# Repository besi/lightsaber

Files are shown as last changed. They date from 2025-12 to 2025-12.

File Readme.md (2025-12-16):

# Lightsaber

This is my lightsaber featuring a custom made PCB and as Neopixel strip.

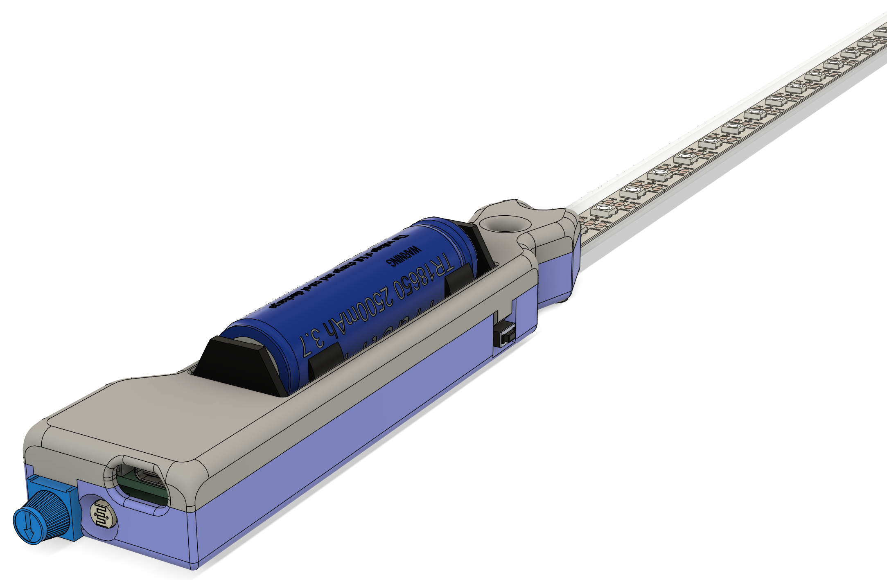
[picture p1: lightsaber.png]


## Pinout of the wemos c3 pico

| Function | Pin |
|---|----:|
| Neopixelstrip | 2 |
| Mode button | 5 |
| Internal RGB* | 7 |
| Potentiometer | 1 |
| Batteryvoltage**  | 3 |

\* This is a GRB instead of RGB LED
\** This requires a solder jumper on the back of the C3 board

## Credits

- 3D model of the 18650 battery by John Michael Loeffler

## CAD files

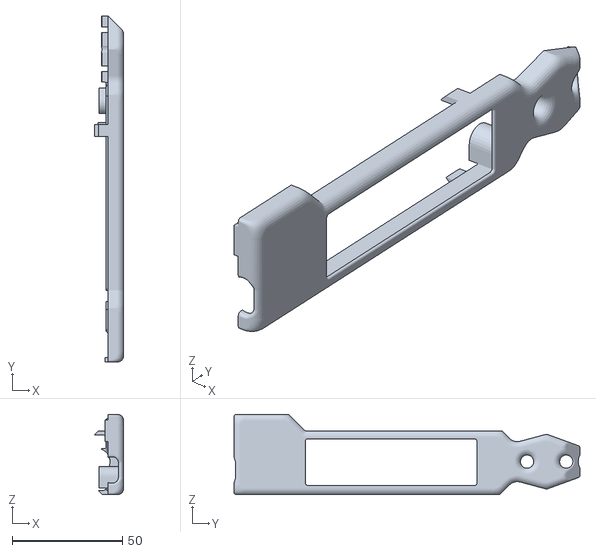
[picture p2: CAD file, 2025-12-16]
stl/top.stl
13.3 x 157.2 x 36.5

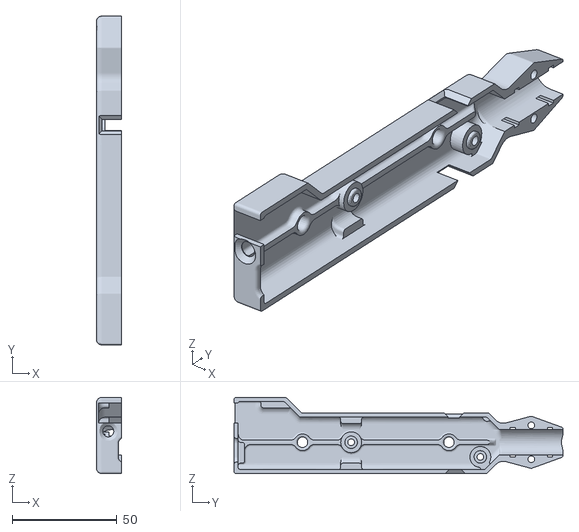
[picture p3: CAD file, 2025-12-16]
stl/bottom.stl
12.0 x 157.2 x 36.5

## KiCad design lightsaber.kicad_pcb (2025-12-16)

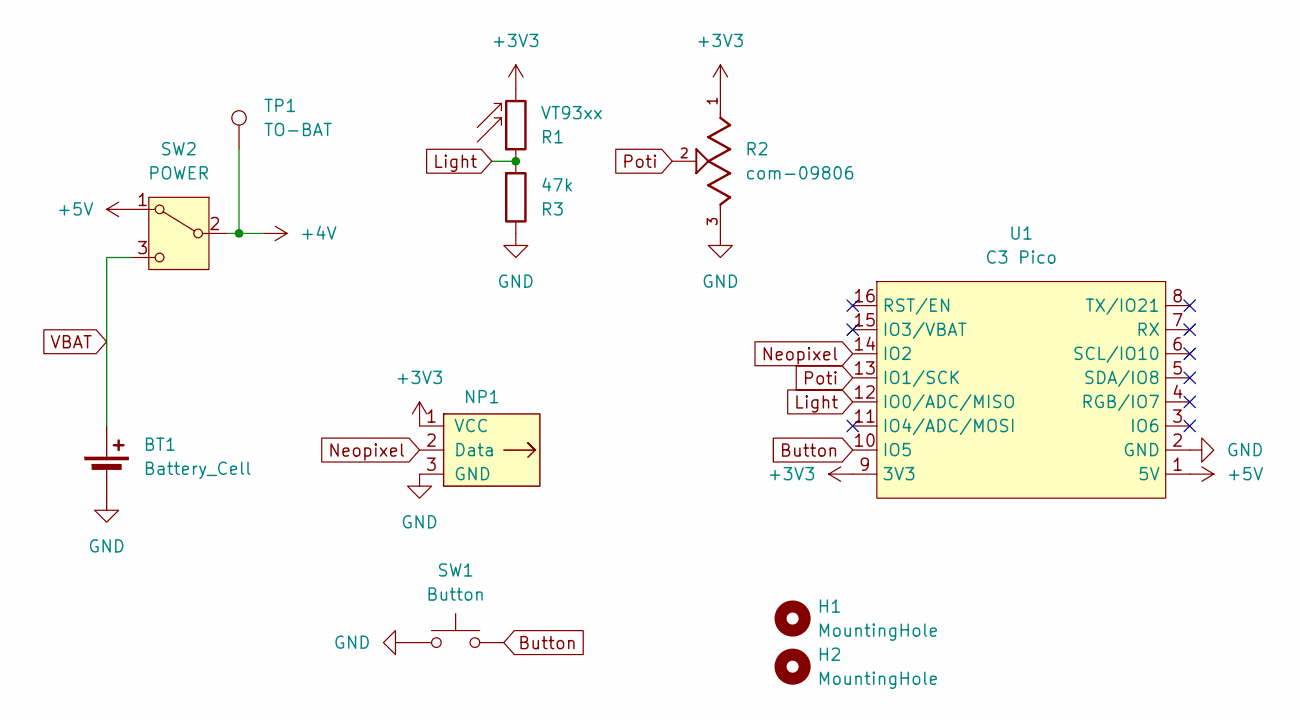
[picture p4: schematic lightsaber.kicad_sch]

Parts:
BT1: Battery_Cell; BatteryHolder_MPD_BH-18650-PC2
H1, H2: MountingHole; MountingHole_3.2mm_M3
NP1: LEDs_Out; neopixel-strip
R1: VT93xx; R_LDR_5.1x4.3mm_P3.4mm_Vertical
R2: com-09806
R3: 47k; R_0805_2012Metric_Pad1.20x1.40mm_HandSolder
SW1: Button; pts636
SW2: POWER; SW_SPDT_CK_JS102011SAQN
TP1: TO-BAT; TestPoint_Loop_D2.50mm_Drill1.0mm
U1: C3 Pico; c3-pico

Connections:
+3V3: NP1.1 (VCC), R1.2, R2.1, U1.9 (3V3)
+4V: SW2.2 (B), TP1.1
+5V: SW2.1 (A), U1.1 (5V)
Button: SW1.2, U1.10 (IO5)
GND: BT1.2 (-), NP1.3 (GND), R2.3, R3.1, SW1.1, U1.2 (GND)
Light: R1.1, R3.2, U1.12 (IO0/ADC/MISO)
Neopixel: NP1.2 (Data), U1.14 (IO2)
Poti: R2.2, U1.13 (IO1/SCK)
VBAT: BT1.1 (+), SW2.3 (C)

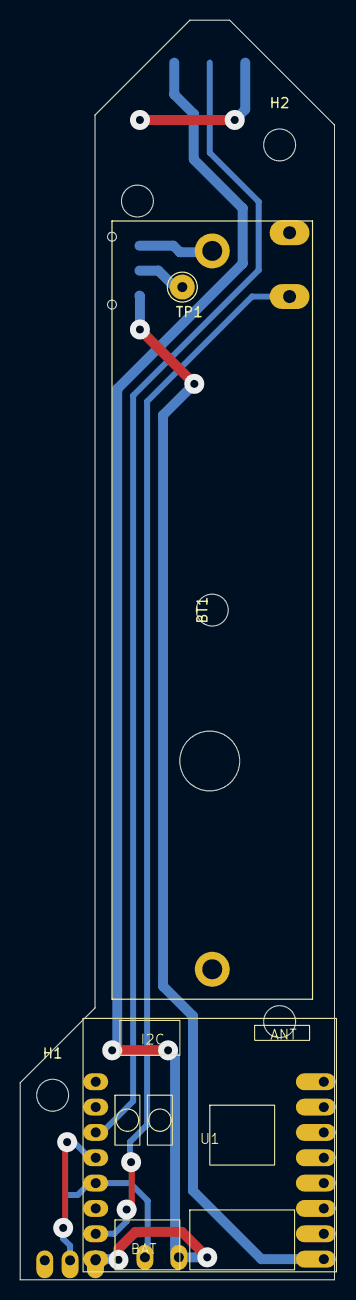
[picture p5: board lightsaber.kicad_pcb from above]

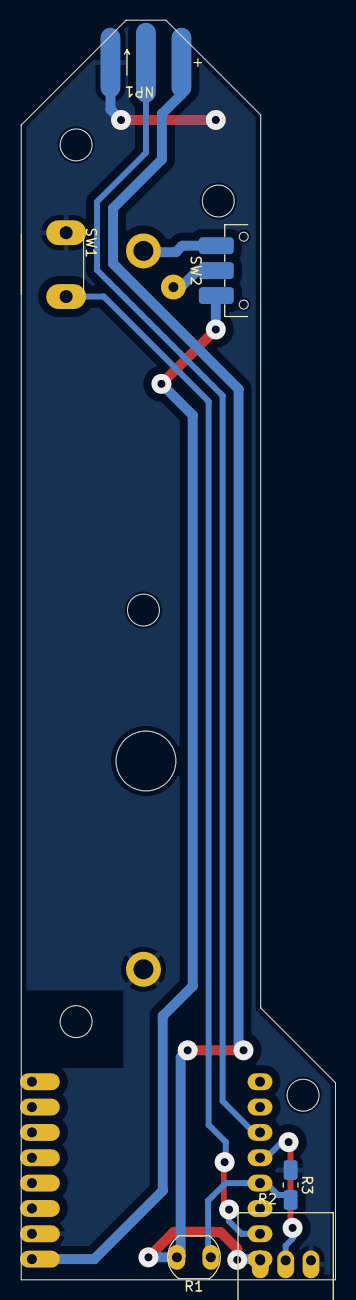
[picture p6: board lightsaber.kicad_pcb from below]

Board: 2 copper layers, 31.5 x 126.2 mm, 11 parts (6 on the bottom side), 9 nets.

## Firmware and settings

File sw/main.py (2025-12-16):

import machine
import time
from machine import Pin, ADC
from neopixel import NeoPixel
from time import sleep


pixel_count = 48
button_pin = 5

if machine.unique_id().hex() == '68b6b3bc4128':
    pixel_count = 74
    button_pin = 4

PRESSED = 0
animate_delay = 0.008
strip_pin = 2
poti_pin = 1

purple = (128,0,128)
blue = (0,0,255)
red = (255,0,0)
yellow = (150,105,0)
green = (0,255,0)
white = (85,85,85)

color_index = 0
colors = [blue, red, yellow, purple, green, white]

current_color = colors[color_index]
last_color = colors[len(colors)-1]

np = NeoPixel(Pin(strip_pin), pixel_count)
np1 = NeoPixel(Pin(7),1) 
button = Pin(button_pin, Pin.IN, Pin.PULL_UP)

poti = ADC(poti_pin)

def next_color(store = True):
    global color_index
    index = color_index
    index += 1
    index = index % len(colors)
    if store:
        color_index = index
    return colors[index]

def dim_factor():
    return int(poti.read() * 77 / 4095) + 1
    
def clear(fade = False):
    if fade:
        c = last_color
        c = dim(c, dim_factor())
        for x in range(max(c)+1):
            n = ((max(c[0] - x,0), max(c[1] - x, 0), max(c[2] - x, 0) ))
            np.fill(n)
            np.write()
    else:
        np.fill((0,0,0))
        np1.fill((0,0,0))
        np.write()
        np1.write()

        
def show(c, animated = True):
    color = dim(c, dim_factor())
    brightness = dim_factor()
    if animated:
        for x in range(pixel_count - 1):
            np[x] = color
            np[pixel_count -1 - x] = color
            np.write()
            sleep(animate_delay)
    else:
        np.fill(color)
        np.write()

        
def wait_for_button():
    while button() != PRESSED:
        sleep(.01)

def dim(c, f=100):
    return (( max(int(c[0]/f),0), max(int(c[1]/f),0), max(int(c[2]/f),0) ))
 
def swap(c):
    return ((c[1], c[0], c[2]))

def status(c):
    np1.fill(swap(c))
    np1.write()
 
clear()
state = 'start'
status(dim(current_color))


while True:
    
    if state == 'start':
        wait_for_button()
        status(dim(next_color(False)))
        show(current_color)
        state = 'light'
        print("state = light")
        last_color = current_color

    elif state == 'light':
        if button() != PRESSED:
            show(current_color, False)
        elif button() == PRESSED:
            clear(True)
            state = 'start'
            print("state = start")
            current_color = next_color(True)

            sleep(.2)
    sleep(.1)

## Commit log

2025-12-10 Initial commit with various footprints
    [lightsaber.kicad_pcb, lightsaber.kicad_sch]
2025-12-10 Update c3 pico library
2025-12-10 Preliminary PCB layout
    [lightsaber.kicad_pcb, lightsaber.kicad_sch]
2025-12-10 Add grid origin for step export
    [lightsaber.kicad_pcb]
2025-12-11 Update PCB for Lightsaber
    [lightsaber.kicad_pcb, lightsaber.kicad_sch]
2025-12-11 Fixed switch between 5V and V_Batt
    [lightsaber.kicad_pcb, lightsaber.kicad_sch]
2025-12-11 Fix edge component placements
    [lightsaber.kicad_pcb]
2025-12-11 Manage the last and current color
2025-12-11 Make sure that the neopixel does not drain the battery so use 3V3 instead of VBAT
    [lightsaber.kicad_pcb, lightsaber.kicad_sch]
2025-12-13 Specify light sensor and its resistor
    [lightsaber.kicad_pcb, lightsaber.kicad_sch]
2025-12-15 Change pinout, add m3 mounting holes
    [lightsaber.kicad_pcb, lightsaber.kicad_sch]
2025-12-15 Cleanup pcb
    [lightsaber.kicad_pcb]
2025-12-15 Add Readme.md and stl files
    [bottom.stl, top.stl]
2025-12-15 Fix pin 5 does not allow ADC
    [lightsaber.kicad_pcb]
2025-12-15 Fix pin mapping - WARNING the old hardware has different pins assigned
    [main.py]
2025-12-15 Reverse the polarity of the slide switch
    [lightsaber.kicad_pcb, lightsaber.kicad_sch]
2025-12-16 Denote the ADC pins
    And change the pinout for the light sensor
    [lightsaber.kicad_pcb, lightsaber.kicad_sch]
2025-12-16 Ambient light sensor does not work
    opens #1
